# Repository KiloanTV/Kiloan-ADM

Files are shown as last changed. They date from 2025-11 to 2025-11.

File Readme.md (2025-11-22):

<div>
  <h1 align="center">Kiloan ADM V1</h1>

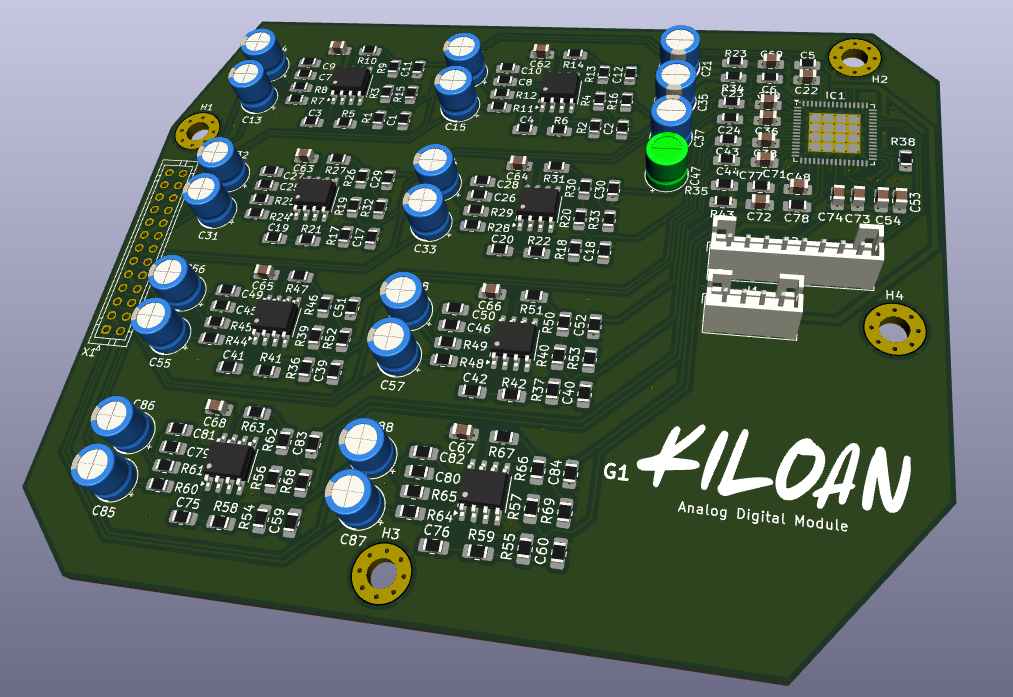
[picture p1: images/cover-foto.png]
Kiloan-ADM
  

  <p align="center">
  <a href="https://blueprint.hackclub.com/">
    
  </a>
  </p>
  <h1></h1>
  <p align="center">
    A 8-Channel Analog to Digital Converter for my custom digital mixing console!
  </p>
</div>

<sub align="center">This work is licensed under the
[MIT License](https://mit-license.org).
</sub>

## Table of Contents

- [About](#about)
- [Pictures](#pictures)
- [Bill of Materials](#bill-of-materials)

# About

I've always wanted my own digital mixing console, but those things are just too expensive for teenagers. That's why I want to build my own! This is the expansion board for 8 analog inputs, it receives power from the motherboard and outputs digital signals via the expansion connector to the Kiloan-APU board.

# Pictures

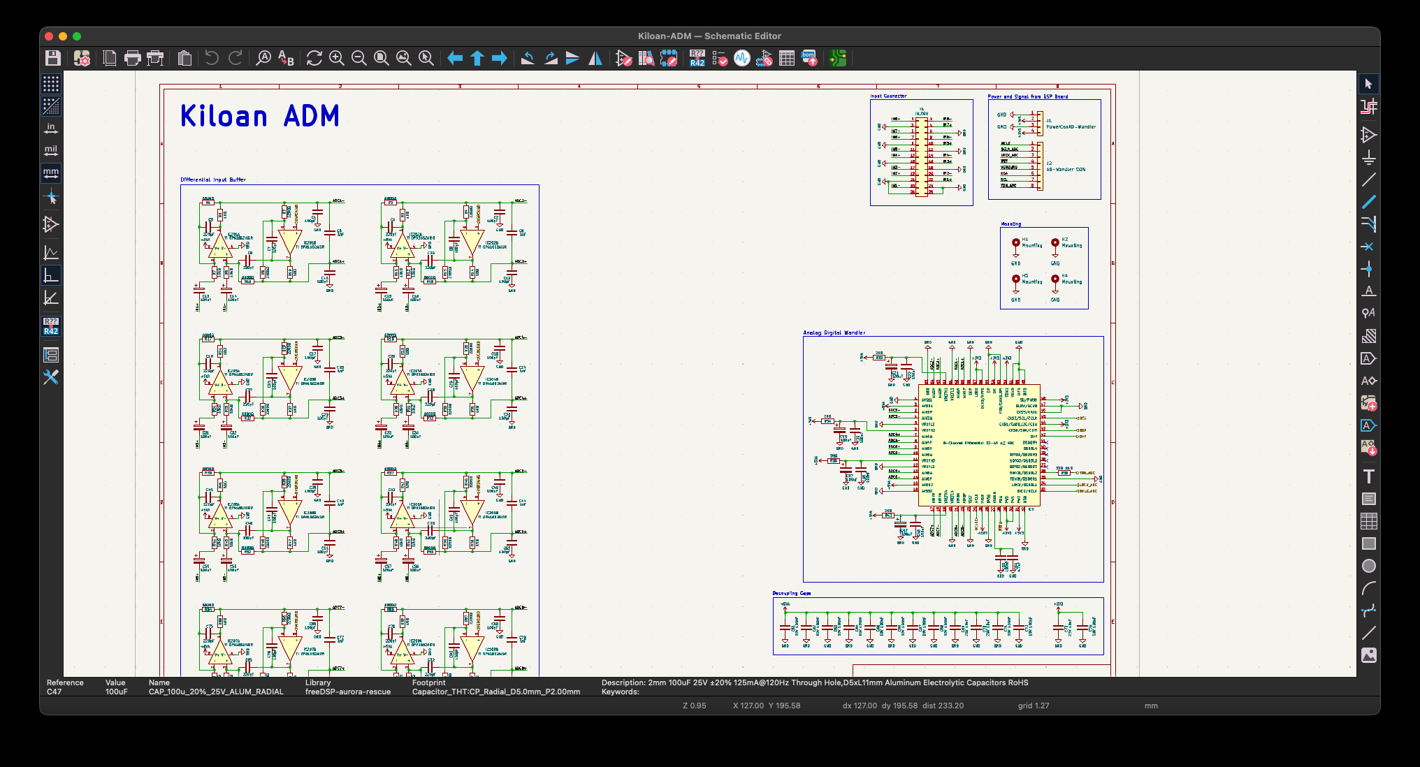
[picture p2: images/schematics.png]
schematics


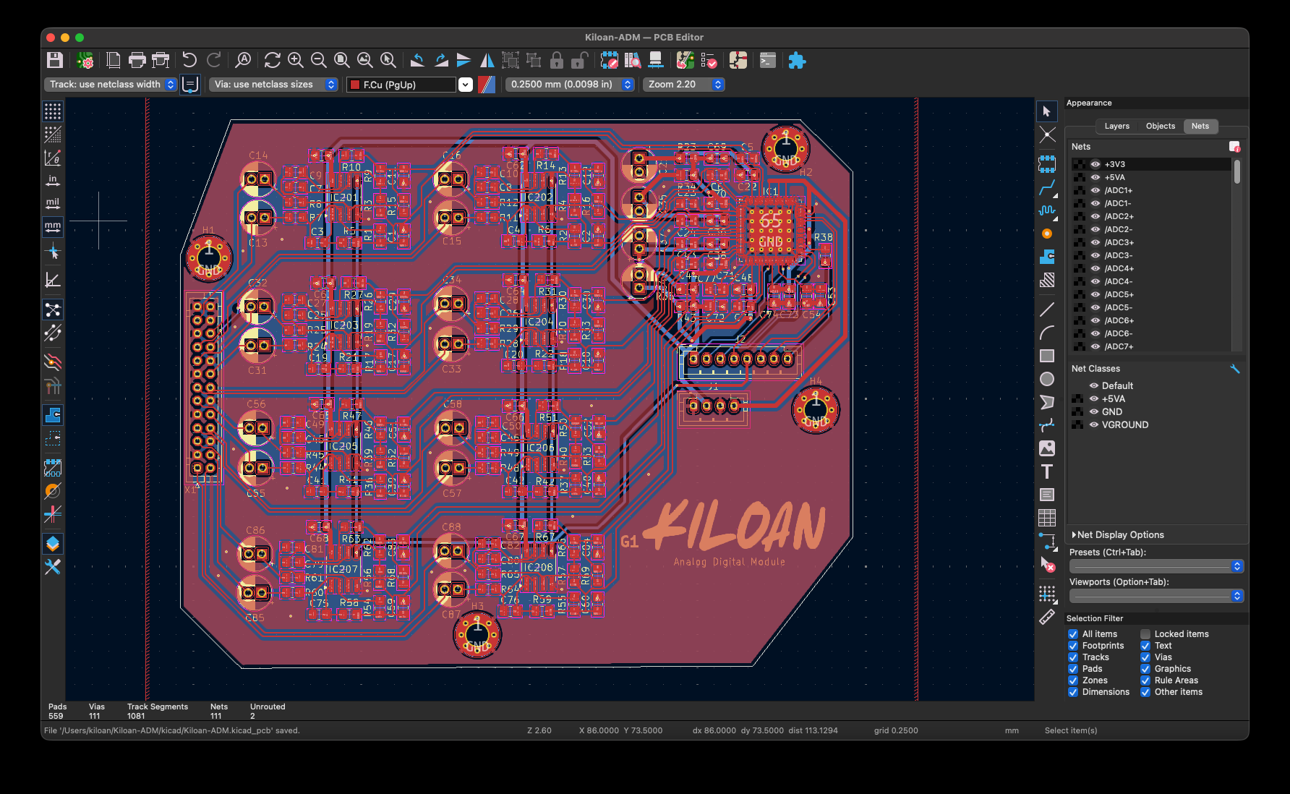
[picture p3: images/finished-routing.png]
pcb


# Bill of Materials

<details>
<summary><strong>Show Bill Of Materials(BOM) ----></strong></summary>

|Designator |Footprint |Quantity|Value |LCSC Part #|
|---|---|---|---|---|
|C1, C11, C12, C17, C18, C2, C25, C26, C29, C30, C39, C40, C45, C46, C51, C52, C59, C60, C7, C79, C8, C80, C83, C84|0805 |24 |100pF |C2167185 |
|C10, C19, C20, C27, C28, C3, C4, C41, C42, C49, C50, C75, C76, C81, C82, C9 |0805 |16 |220pF |C569853 |
|C13, C14, C15, C16, C21, C31, C32, C33, C34, C35, C37, C47, C55, C56, C57, C58, C85, C86, C87, C88 |CP_Radial_D5.0mm_P2.00mm |20 |100uF |C136287 |
|C22, C36, C38, C48, C53 |0805 |5 |100nF |C3018562 |
|C23, C24, C43, C44, C5, C6, C77, C78 |0805 |8 |1nF |C178423 |
|C54 |0805 |1 |4.7uF |C162418 |
|C61, C62, C63, C64, C65, C66, C67, C68, C71, C72, C74 |0805 |11 |50V 100nF |C3018562 |
|C69, C70, C73 |0805 |3 |25V 10uF |C391262 |
|IC1 |QFN-64-1EP_9x9mm_P0.5mm_EP6x6mm_ThermalVias|1 |8-Channel Differential 32-bit △∑ ADC|C2655448 |
|IC201, IC202, IC203, IC204, IC205, IC206, IC207, IC208 |SOIC-8_3.9x4.9mm_P1.27mm |8 |TI OPA1652AIDR | |
|J1 |JST_PH_B4B-PH-K_1x04_P2.00mm_Vertical |1 |PowerConAD-Wandler |C131334 |
|J2 |JST_PH_B8B-PH-K_1x08_P2.00mm_Vertical |1 |AD-Wandler CON |C157974 |
|R1, R15, R16, R17, R18, R2, R32, R33, R36, R37, R52, R53, R54, R55, R68, R69 |0805 |16 |6800Ω |C2092414 |
|R10, R14, R21, R22, R27, R31, R41, R42, R47, R5, R51, R58, R59, R6, R63, R67 |0805 |16 |10Ω |C2479122 |
|R11, R12, R24, R25, R28, R29, R44, R45, R48, R49, R60, R61, R64, R65, R7, R8 |0805 |16 |10kΩ |C2441435 |
|R13, R19, R20, R26, R3, R30, R39, R4, R40, R46, R50, R56, R57, R62, R66, R9 |0805 |16 |2200Ω |C2085959 |
|R23, R34, R35, R43 |0805 |4 |20Ω |C114557 |
|R38 |0805 |1 |33Ω ±1% |C126353 |
|X1 |JST_PHD_B26B-PHDSS_2x13_P2.00mm_Vertical |1 |IN_CON |C3011993 |
| LCSC Quote: 47,54 Dollar + JLCPCP Quote: 27,65 Dollar | | | | |

</details>

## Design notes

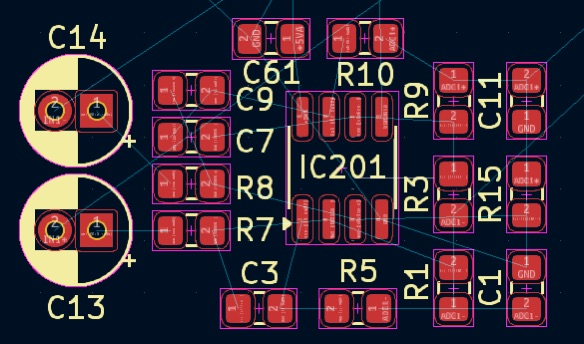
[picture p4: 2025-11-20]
images/buffer2.jpeg

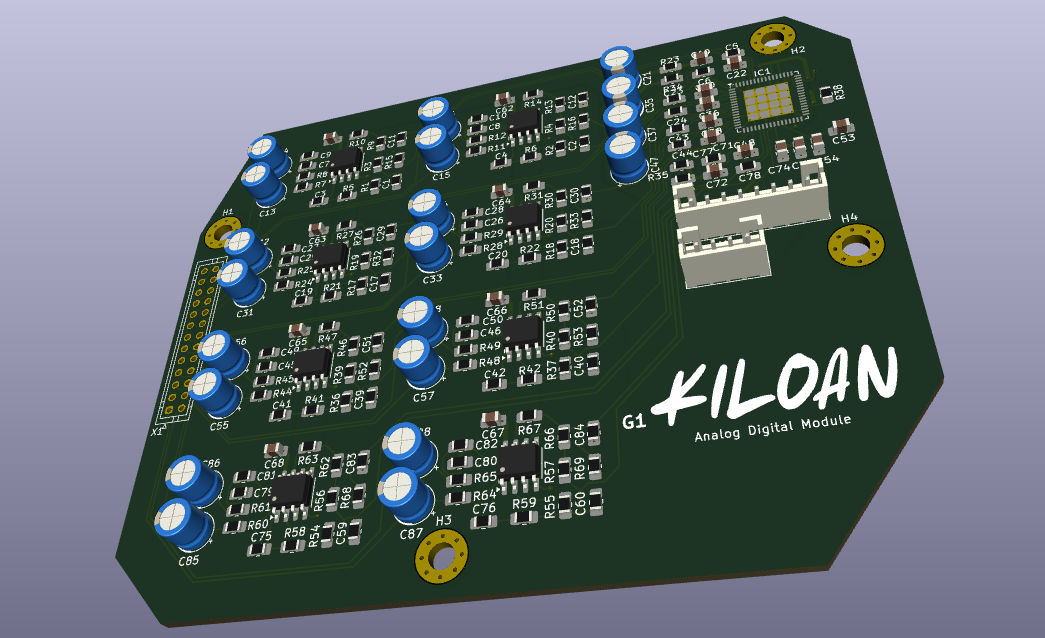
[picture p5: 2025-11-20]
images/routing.png

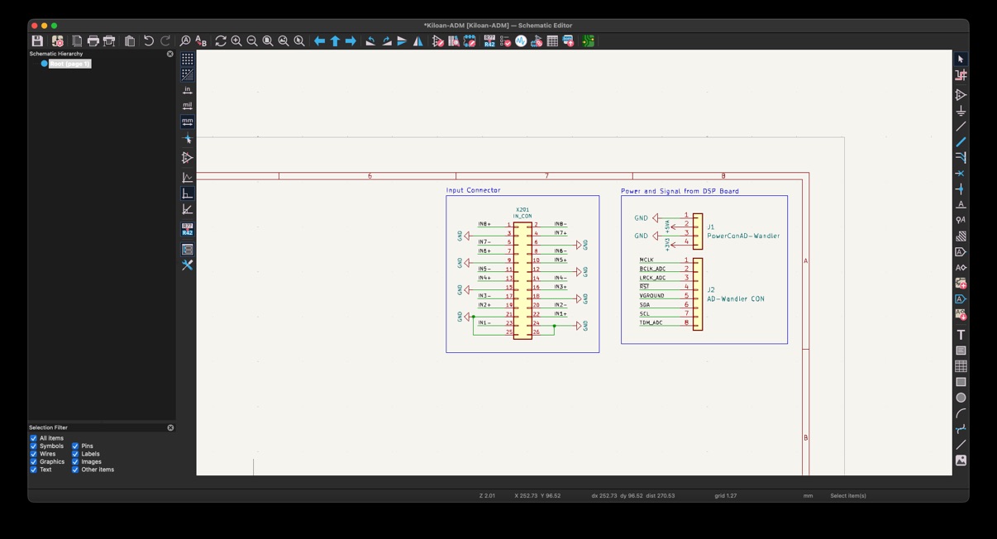
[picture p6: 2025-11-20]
images/input-con.jpeg

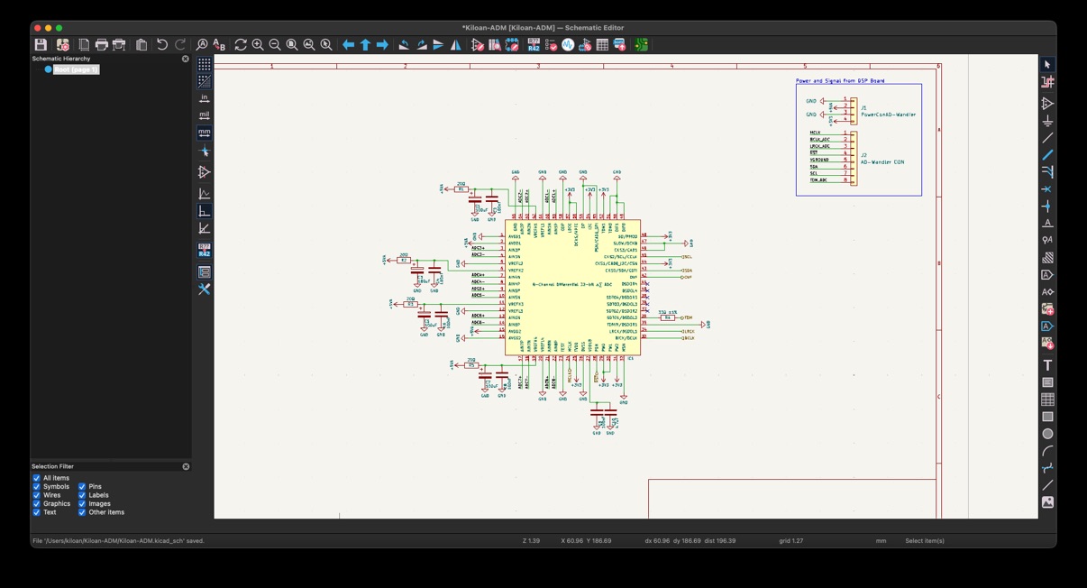
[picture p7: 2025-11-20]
images/adc-wandler.jpeg

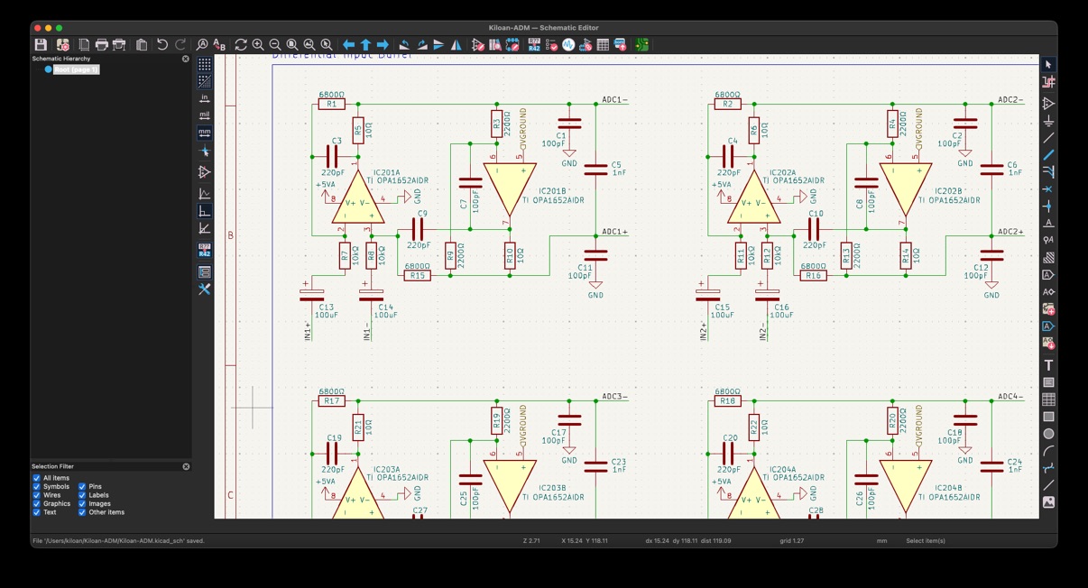
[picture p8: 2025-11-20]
images/buffer.jpeg

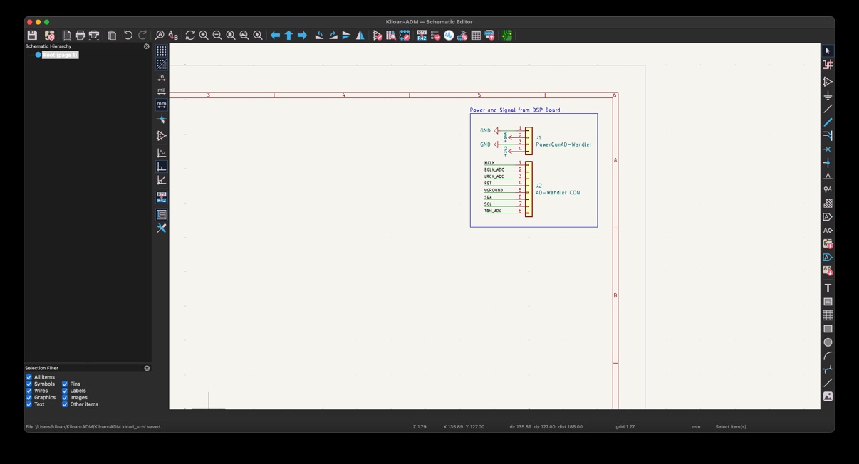
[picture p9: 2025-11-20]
images/power-signal.jpeg

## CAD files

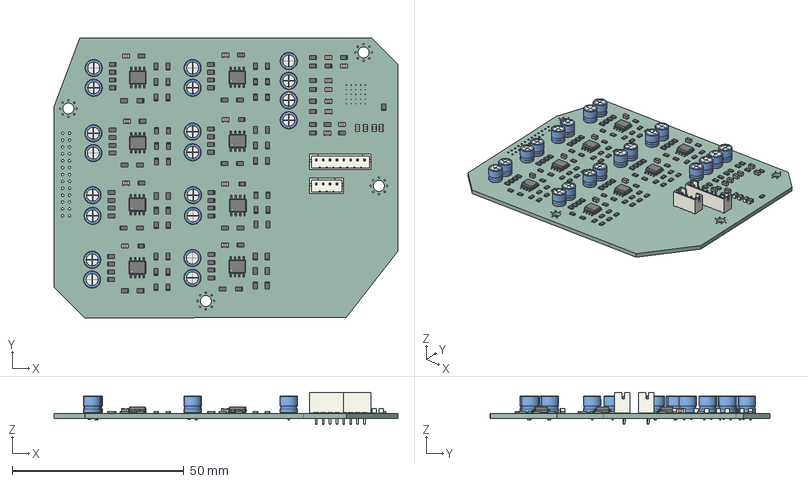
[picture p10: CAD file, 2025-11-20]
cad/Kiloan-ADM_pcb.step
100.0 x 81.5 x 9.40 mm
R_0805_2012Metric x 117
C_0805_2012Metric x 20
CP_Radial_D5.0mm_P2.00mm x 20
JST_PH_B4B-PH-K_1x04_P2.00mm_Vertical
SOIC-8_3.9x4.9mm_P1.27mm x 8
JST_PH_B8B-PH-K_1x08_P2.00mm_Vertical
Kiloan-ADM_PCB

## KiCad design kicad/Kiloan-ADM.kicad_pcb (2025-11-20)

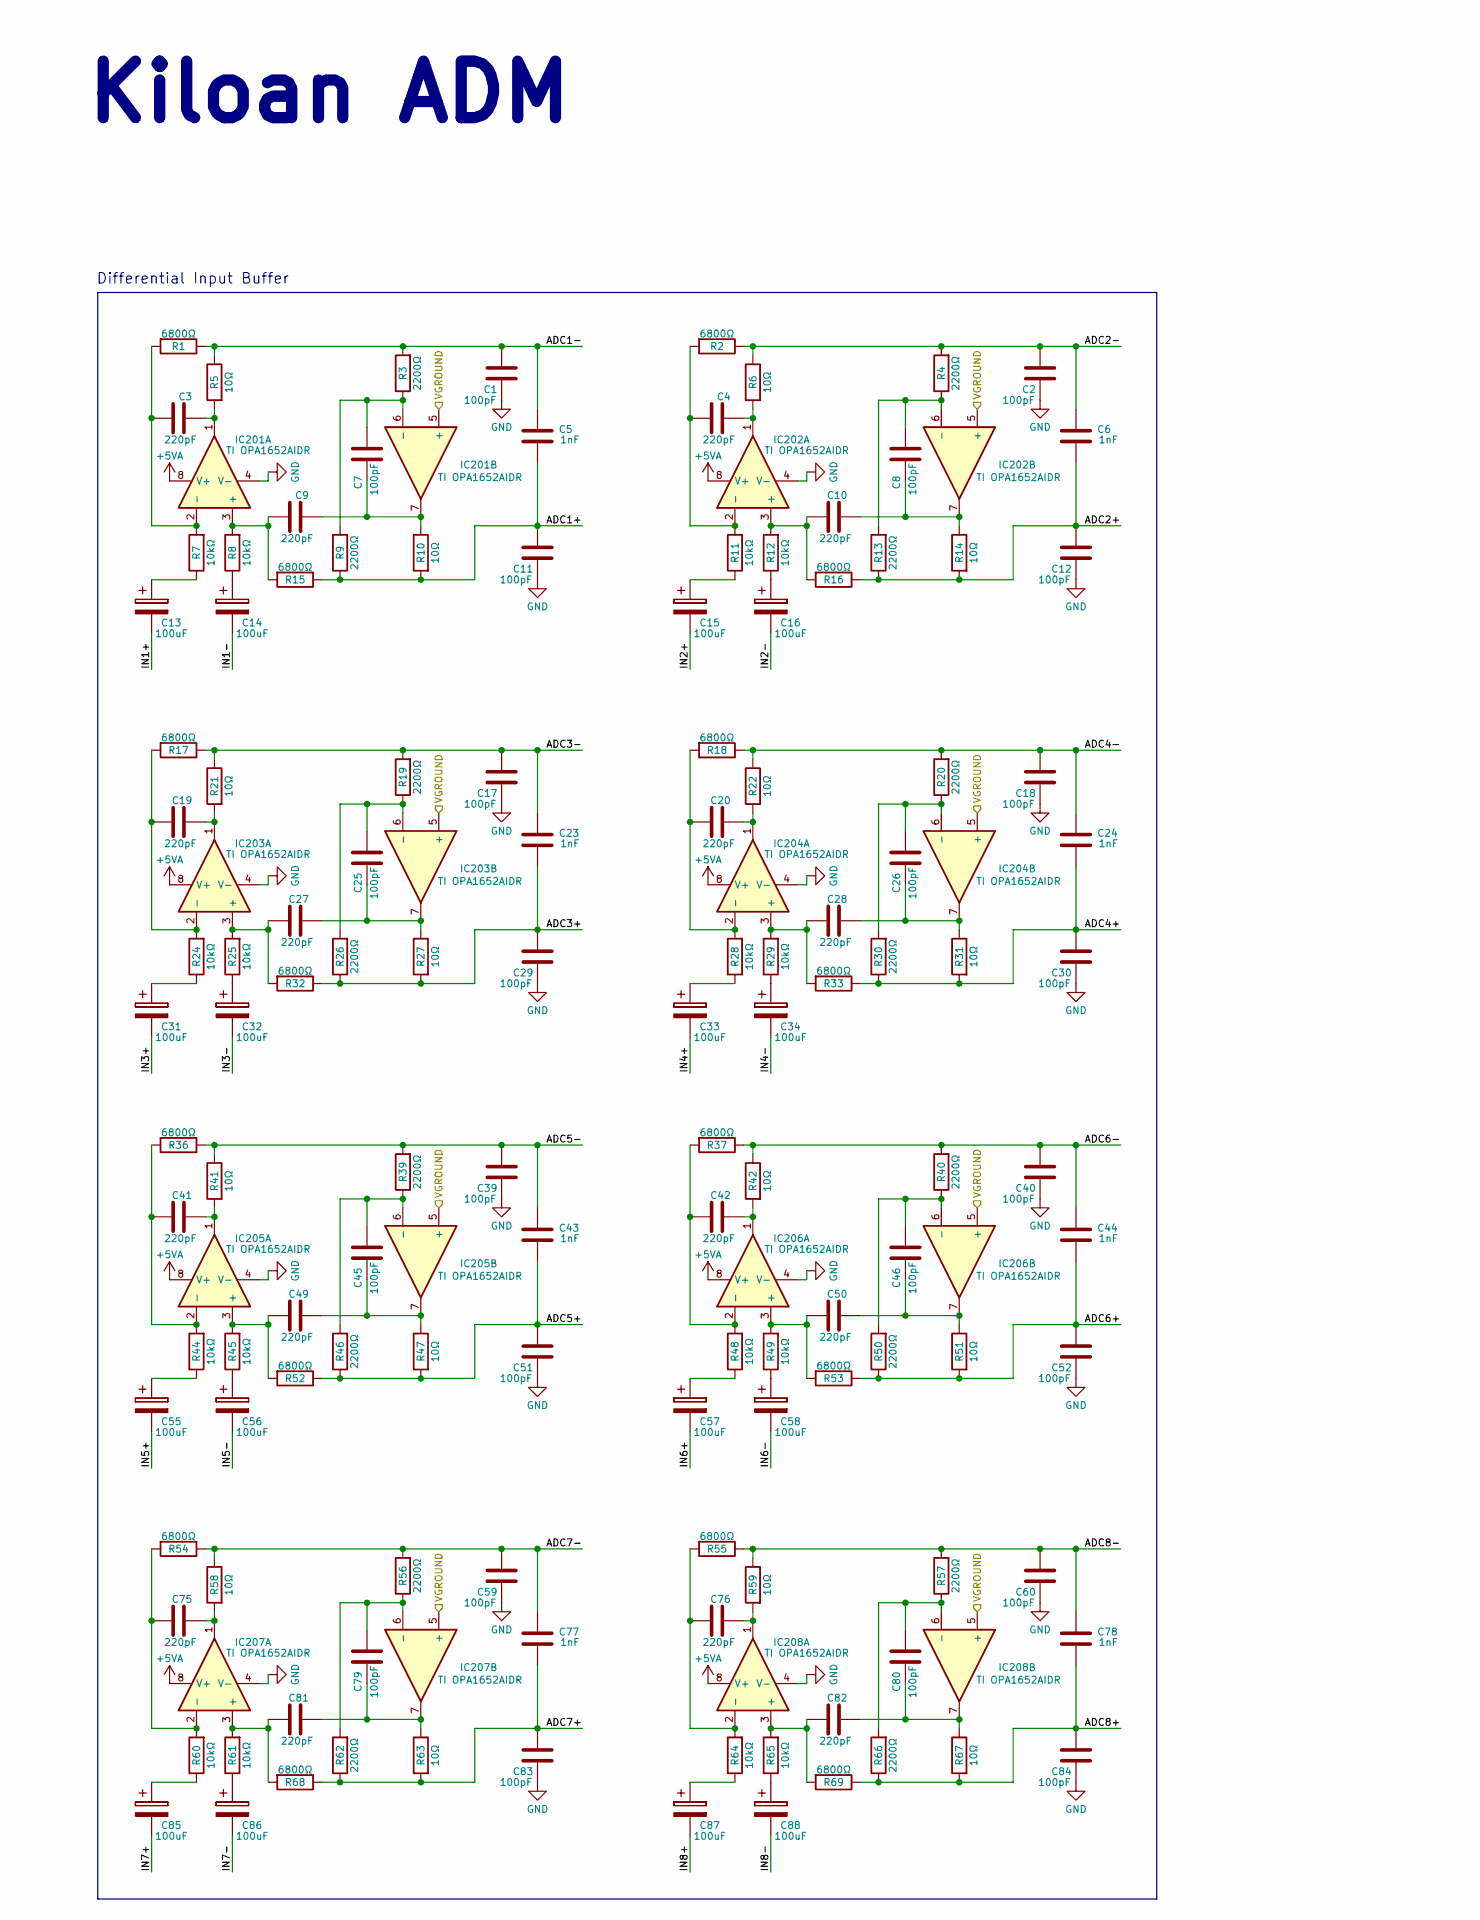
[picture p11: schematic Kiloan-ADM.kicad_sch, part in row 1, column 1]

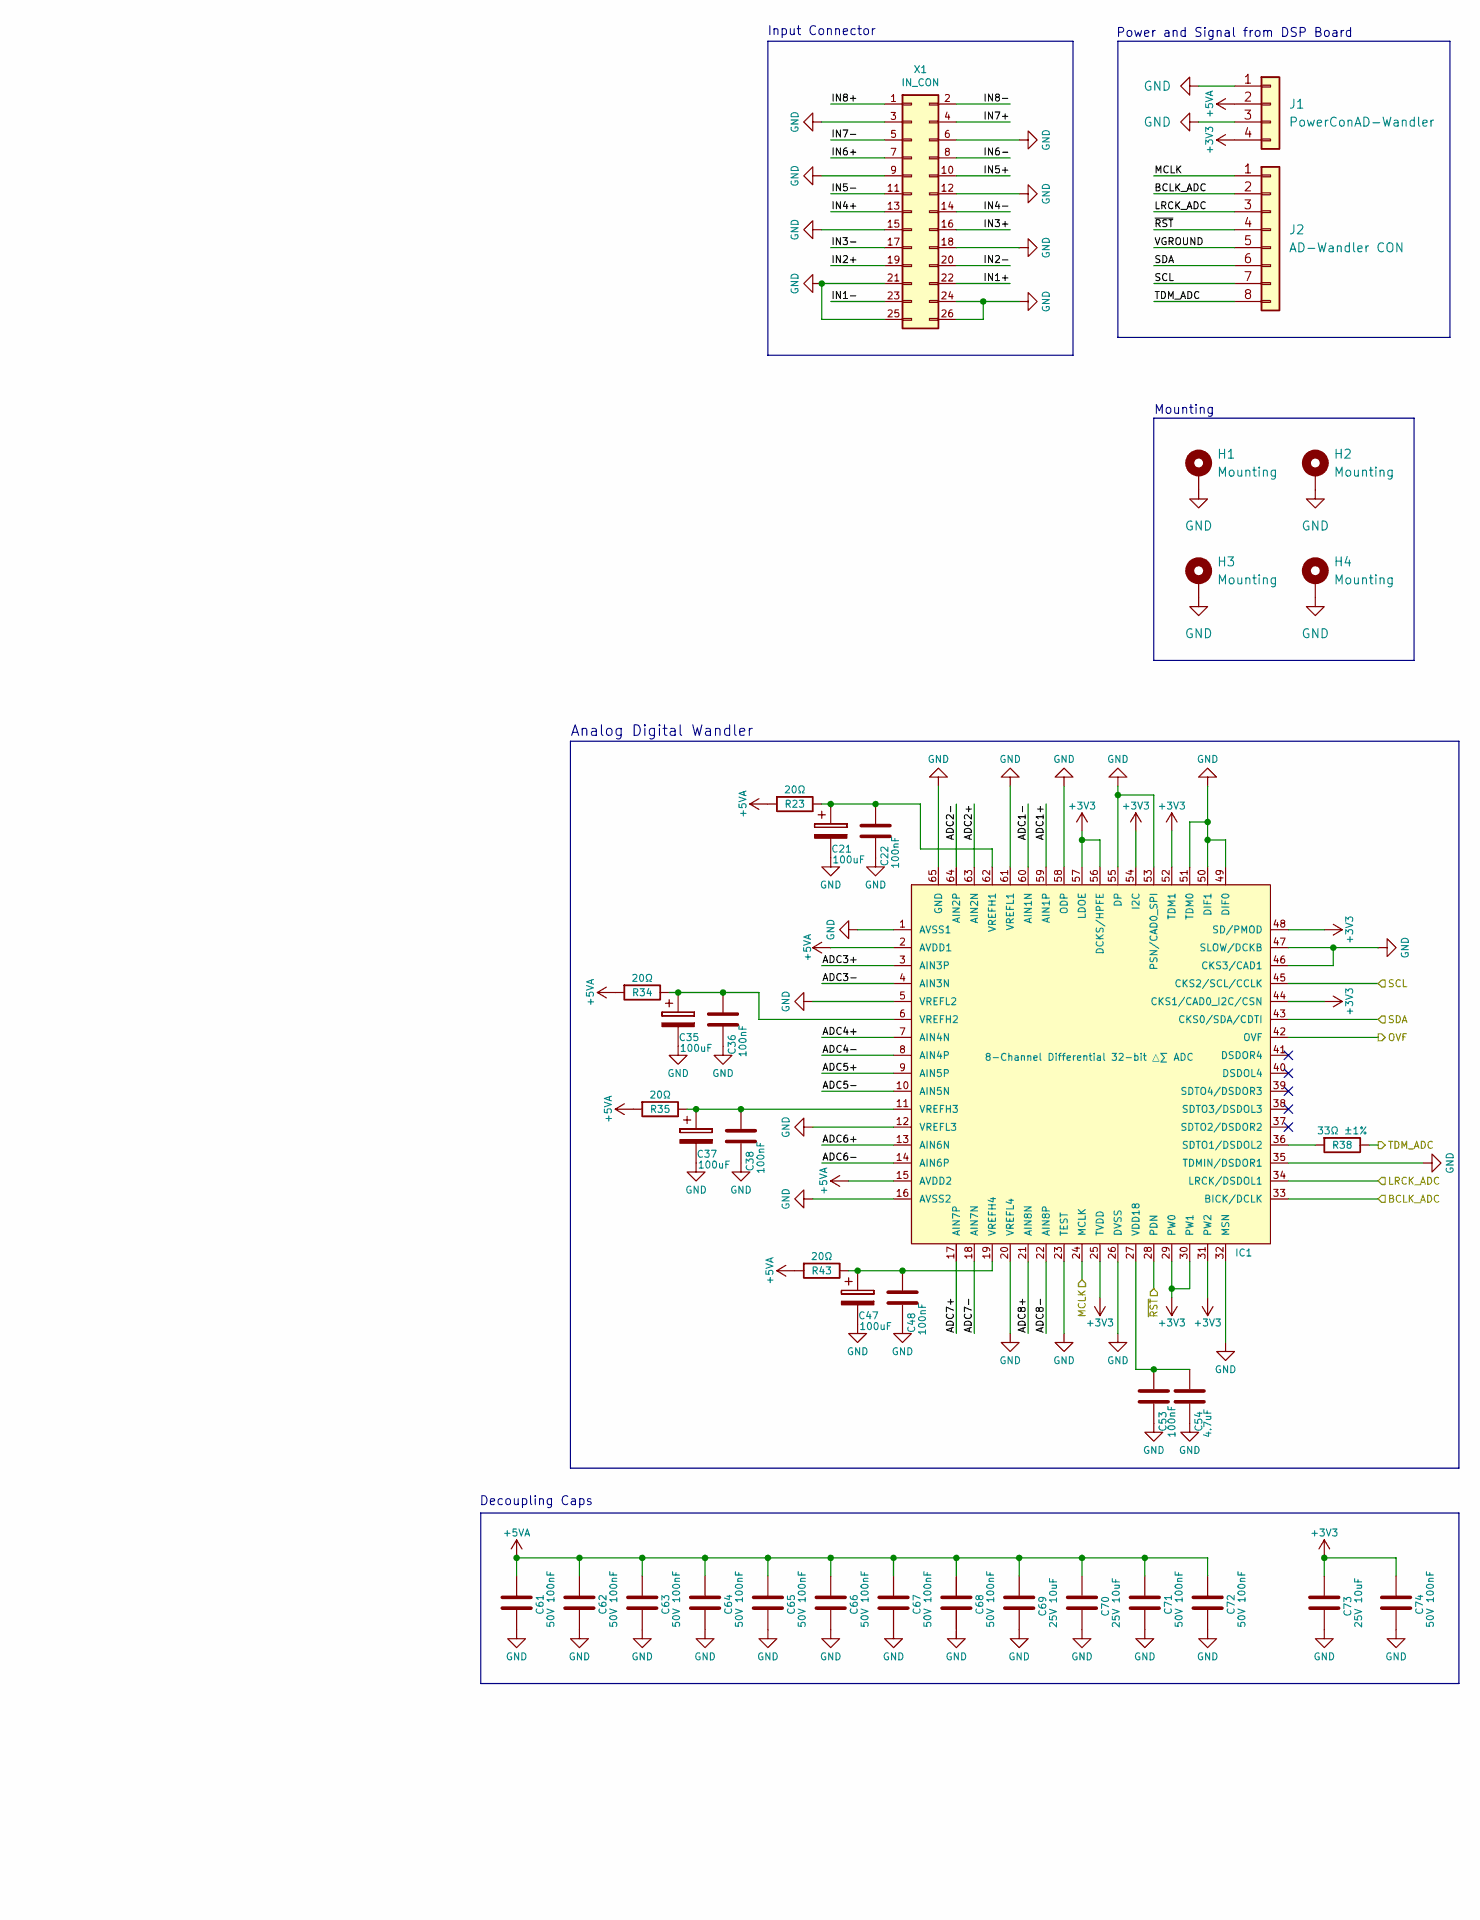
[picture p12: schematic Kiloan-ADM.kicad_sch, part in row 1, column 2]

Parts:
C1, C2, C7, C8, C11, C12, C17, C18, C25, C26, C29, C30, C39, C40, C45, C46, C51, C52, C59, C60, C79, C80, C83, C84: 100pF; R_0805_2012Metric_Pad1.20x1.40mm_HandSolder; LCSC C2167185
C3, C4, C9, C10, C19, C20, C27, C28, C41, C42, C49, C50, C75, C76, C81, C82: 220pF; R_0805_2012Metric_Pad1.20x1.40mm_HandSolder; LCSC C569853
C5, C6, C23, C24, C43, C44, C77, C78: 1nF; R_0805_2012Metric_Pad1.20x1.40mm_HandSolder; LCSC C178423
C13, C14, C15, C16, C21, C31, C32, C33, C34, C35, C37, C47, C55, C56, C57, C58, C85, C86, C87, C88: 100uF; CP_Radial_D5.0mm_P2.00mm; LCSC C136287
C22, C36, C38, C48, C53: 100nF; C_0805_2012Metric_Pad1.18x1.45mm_HandSolder; LCSC C3018562
C54: 4.7uF; C_0805_2012Metric_Pad1.18x1.45mm_HandSolder; LCSC C162418
C61, C62, C63, C64, C65, C66, C67, C68, C71, C72, C74: 50V 100nF; C_0805_2012Metric_Pad1.18x1.45mm_HandSolder; LCSC C3018562
C69, C70, C73: 25V 10uF; C_0805_2012Metric_Pad1.18x1.45mm_HandSolder; LCSC C391262
H1, H2, H3, H4: Mounting; MountingHole_3.2mm_M3_Pad_Via
IC1: 8-Channel Differential 32-bit △∑ ADC; QFN-64-1EP_9x9mm_P0.5mm_EP6x6mm_ThermalVias; LCSC C2655448
IC201, IC202, IC203, IC204, IC205, IC206, IC207, IC208: TI OPA1652AIDR; SOIC-8_3.9x4.9mm_P1.27mm
J1: PowerConAD-Wandler; JST_PH_B4B-PH-K_1x04_P2.00mm_Vertical; LCSC C131334
J2: AD-Wandler CON; JST_PH_B8B-PH-K_1x08_P2.00mm_Vertical; LCSC C157974
R1, R2, R15, R16, R17, R18, R32, R33, R36, R37, R52, R53, R54, R55, R68, R69: 6800Ω; R_0805_2012Metric_Pad1.20x1.40mm_HandSolder; LCSC C2092414
R3, R4, R9, R13, R19, R20, R26, R30, R39, R40, R46, R50, R56, R57, R62, R66: 2200Ω; R_0805_2012Metric_Pad1.20x1.40mm_HandSolder; LCSC C2085959
R5, R6, R10, R14, R21, R22, R27, R31, R41, R42, R47, R51, R58, R59, R63, R67: 10Ω; R_0805_2012Metric_Pad1.20x1.40mm_HandSolder; LCSC C2479122
R7, R8, R11, R12, R24, R25, R28, R29, R44, R45, R48, R49, R60, R61, R64, R65: 10kΩ; R_0805_2012Metric_Pad1.20x1.40mm_HandSolder; LCSC C2441435
R23, R34, R35, R43: 20Ω; R_0805_2012Metric_Pad1.20x1.40mm_HandSolder; LCSC C114557
R38: 33Ω ±1%; R_0805_2012Metric_Pad1.20x1.40mm_HandSolder; LCSC C126353
X1: IN_CON; JST_PHD_B26B-PHDSS_2x13_P2.00mm_Vertical; LCSC C3011993

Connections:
+3V3: C73.1, C74.1, IC1.25 (TVDD), IC1.29 (PW0), IC1.30 (PW1), IC1.31 (PW2), IC1.44 (CKS1/CAD0_I2C/CSN), IC1.48 (SD/PMOD), IC1.52 (TDM1), IC1.54 (I2C), IC1.56 (DCKS/HPFE), IC1.57 (LDOE), J1.4 (3V3)
+5VA: C61.1, C62.1, C63.1, C64.1, C65.1, C66.1, C67.1, C68.1, C69.1, C70.1, C71.1, C72.1, IC1.2 (AVDD1), IC1.15 (AVDD2), IC201.8 (V+), IC202.8 (V+), IC203.8 (V+), IC204.8 (V+), IC205.8 (V+), IC206.8 (V+), IC207.8 (V+), IC208.8 (V+), J1.2 (5VA), R23.2, R34.2, R35.2, R43.2
/ADC1+: C5.2, C11.2, IC1.59 (AIN1P), R9.1, R10.2, R15.1
/ADC1-: C1.2, C5.1, IC1.60 (AIN1N), R1.1, R3.2, R5.1
/ADC2+: C6.2, C12.2, IC1.63 (AIN2N), R13.1, R14.2, R16.1
/ADC2-: C2.2, C6.1, IC1.64 (AIN2P), R2.1, R4.2, R6.1
/ADC3+: C23.2, C29.2, IC1.3 (AIN3P), R26.1, R27.2, R32.1
/ADC3-: C17.2, C23.1, IC1.4 (AIN3N), R17.1, R19.2, R21.1
/ADC4+: C24.2, C30.2, IC1.7 (AIN4N), R30.1, R31.2, R33.1
/ADC4-: C18.2, C24.1, IC1.8 (AIN4P), R18.1, R20.2, R22.1
/ADC5+: C43.2, C51.2, IC1.9 (AIN5P), R46.1, R47.2, R52.1
/ADC5-: C39.2, C43.1, IC1.10 (AIN5N), R36.1, R39.2, R41.1
/ADC6+: C44.2, C52.2, IC1.13 (AIN6N), R50.1, R51.2, R53.1
/ADC6-: C40.2, C44.1, IC1.14 (AIN6P), R37.1, R40.2, R42.1
/ADC7+: C77.2, C83.2, IC1.17 (AIN7P), R62.1, R63.2, R68.1
/ADC7-: C59.2, C77.1, IC1.18 (AIN7N), R54.1, R56.2, R58.1
/ADC8+: C78.2, C84.2, IC1.21 (AIN8N), R66.1, R67.2, R69.1
/ADC8-: C60.2, C78.1, IC1.22 (AIN8P), R55.1, R57.2, R59.1
/BCLK_ADC: IC1.33 (BICK/DCLK), J2.2 (BCLK)
/IN1+: C13.2, X1.22
/IN1-: C14.2, X1.23
/IN2+: C15.2, X1.19
/IN2-: C16.2, X1.20
/IN3+: C31.2, X1.16
/IN3-: C32.2, X1.17
/IN4+: C33.2, X1.13
/IN4-: C34.2, X1.14
/IN5+: C55.2, X1.10
/IN5-: C56.2, X1.11
/IN6+: C57.2, X1.7
/IN6-: C58.2, X1.8
/IN7+: C85.2, X1.4
/IN7-: C86.2, X1.5
/IN8+: C87.2, X1.1
/IN8-: C88.2, X1.2
/LRCK_ADC: IC1.34 (LRCK/DSDOL1), J2.3 (LRCK)
/MCLK: IC1.24 (MCLK), J2.1 (MCLK)
/OVF: IC1.42 (OVF)
/SCL: IC1.45 (CKS2/SCL/CCLK), J2.7 (SCL)
/SDA: IC1.43 (CKS0/SDA/CDTI), J2.6 (SDA)
/TDM_ADC: J2.8 (TDM), R38.1
/VGROUND: IC201.5 (+), IC202.5 (+), IC203.5 (+), IC204.5 (+), IC205.5 (+), IC206.5 (+), IC207.5 (+), IC208.5 (+), J2.5 (VGROUND)
/~RST: IC1.28 (PDN), J2.4 (RST)
GND: C1.1, C2.1, C11.1, C12.1, C17.1, C18.1, C21.2, C22.2, C29.1, C30.1, C35.2, C36.2, C37.2, C38.2, C39.1, C40.1, C47.2, C48.2, C51.1, C52.1, C53.2, C54.2, C59.1, C60.1, C61.2, C62.2, C63.2, C64.2, C65.2, C66.2, C67.2, C68.2, C69.2, C70.2, C71.2, C72.2, C73.2, C74.2, C83.1, C84.1, H1.1, H2.1, H3.1, H4.1, IC1.1 (AVSS1), IC1.5 (VREFL2), IC1.12 (VREFL3), IC1.16 (AVSS2), IC1.20 (VREFL4), IC1.23 (TEST), IC1.26 (DVSS), IC1.32 (MSN), IC1.35 (TDMIN/DSDOR1), IC1.46 (CKS3/CAD1), IC1.47 (SLOW/DCKB), IC1.49 (DIF0), IC1.50 (DIF1), IC1.51 (TDM0), IC1.53 (PSN/CAD0_SPI), IC1.55 (DP), IC1.58 (ODP), IC1.61 (VREFL1), IC1.65 (GND), IC201.4 (V-), IC202.4 (V-), IC203.4 (V-), IC204.4 (V-), IC205.4 (V-), IC206.4 (V-), IC207.4 (V-), IC208.4 (V-), J1.1 (GND), J1.3 (GND), X1.3, X1.6, X1.9, X1.12, X1.15, X1.18, X1.21, X1.24, X1.25, X1.26
unnamed: C3.2, IC201.1, R5.2
unnamed: C4.2, IC202.1, R6.2
unnamed: C7.1, C9.2, IC201.7, R10.1
unnamed: C8.1, C10.2, IC202.7, R14.1
unnamed: C13.1, R7.1
unnamed: C14.1, R8.1
unnamed: C15.1, R11.1
unnamed: C16.1, R12.1
unnamed: C19.2, IC203.1, R21.2
unnamed: C20.2, IC204.1, R22.2
unnamed: C25.1, C27.2, IC203.7, R27.1
unnamed: C26.1, C28.2, IC204.7, R31.1
unnamed: C31.1, R24.1
unnamed: C32.1, R25.1
unnamed: C33.1, R28.1
unnamed: C34.1, R29.1
unnamed: C41.2, IC205.1, R41.2
unnamed: C42.2, IC206.1, R42.2
unnamed: C45.1, C49.2, IC205.7, R47.1
unnamed: C46.1, C50.2, IC206.7, R51.1
unnamed: C55.1, R44.1
unnamed: C56.1, R45.1
unnamed: C57.1, R48.1
unnamed: C58.1, R49.1
unnamed: C75.2, IC207.1, R58.2
unnamed: C76.2, IC208.1, R59.2
unnamed: C79.1, C81.2, IC207.7, R63.1
unnamed: C80.1, C82.2, IC208.7, R67.1
unnamed: C85.1, R60.1
unnamed: C86.1, R61.1
unnamed: C87.1, R64.1
unnamed: C88.1, R65.1
unnamed: IC1.36 (SDTO1/DSDOL2), R38.2
unnamed: C53.1, C54.1, IC1.27 (VDD18)
unnamed: C21.1, C22.1, IC1.62 (VREFH1), R23.1
unnamed: C35.1, C36.1, IC1.6 (VREFH2), R34.1
unnamed: C37.1, C38.1, IC1.11 (VREFH3), R35.1
unnamed: C47.1, C48.1, IC1.19 (VREFH4), R43.1
unnamed: C9.1, IC201.3 (+), R8.2, R15.2
unnamed: C3.1, IC201.2 (-), R1.2, R7.2
unnamed: C7.2, IC201.6 (-), R3.1, R9.2
unnamed: C10.1, IC202.3 (+), R12.2, R16.2
unnamed: C4.1, IC202.2 (-), R2.2, R11.2
unnamed: C8.2, IC202.6 (-), R4.1, R13.2
unnamed: C27.1, IC203.3 (+), R25.2, R32.2
unnamed: C19.1, IC203.2 (-), R17.2, R24.2
unnamed: C25.2, IC203.6 (-), R19.1, R26.2
unnamed: C28.1, IC204.3 (+), R29.2, R33.2
unnamed: C20.1, IC204.2 (-), R18.2, R28.2
unnamed: C26.2, IC204.6 (-), R20.1, R30.2
unnamed: C49.1, IC205.3 (+), R45.2, R52.2
unnamed: C41.1, IC205.2 (-), R36.2, R44.2
unnamed: C45.2, IC205.6 (-), R39.1, R46.2
unnamed: C50.1, IC206.3 (+), R49.2, R53.2
unnamed: C42.1, IC206.2 (-), R37.2, R48.2
unnamed: C46.2, IC206.6 (-), R40.1, R50.2
unnamed: C81.1, IC207.3 (+), R61.2, R68.2
unnamed: C75.1, IC207.2 (-), R54.2, R60.2
unnamed: C79.2, IC207.6 (-), R56.1, R62.2
unnamed: C82.1, IC208.3 (+), R65.2, R69.2
unnamed: C76.1, IC208.2 (-), R55.2, R64.2
unnamed: C80.2, IC208.6 (-), R57.1, R66.2

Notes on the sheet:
Mounting
Analog Digital Wandler
Kiloan ADM
Input Connector
Power and Signal from DSP Board
Differential Input Buffer
Decoupling Caps

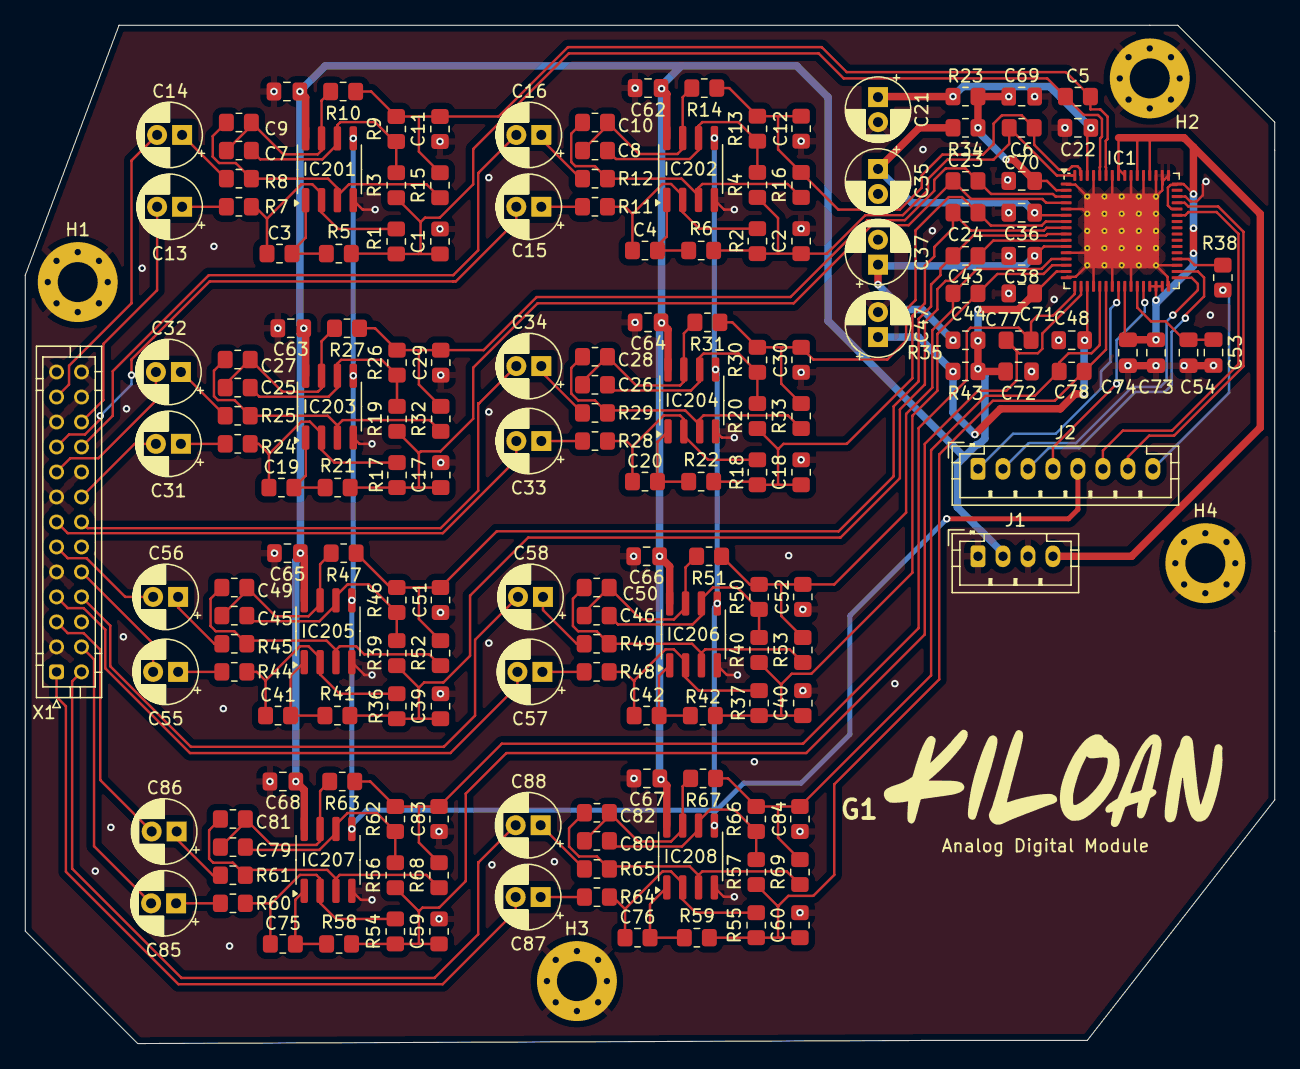
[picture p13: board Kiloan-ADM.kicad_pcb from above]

Board: 2 copper layers, 100.0 x 81.5 mm, 174 parts (0 on the bottom side), 105 nets.

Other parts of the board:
G1: LOGO
